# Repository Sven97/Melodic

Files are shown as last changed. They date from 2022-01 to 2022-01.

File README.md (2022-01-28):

# Melodic

[GitHub Address](https://github.com/Sven97/Melodic)

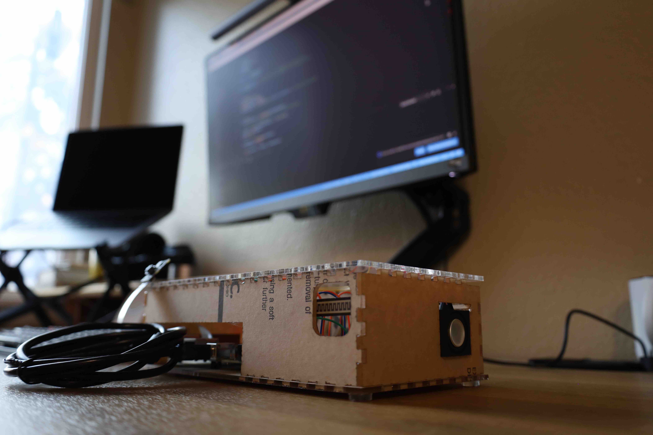
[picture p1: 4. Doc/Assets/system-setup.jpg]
system setup


## 0. About

An integrated system providing speech therapy service via software and hardware at low cost.

This repo contains the code and the instructions for Imagine Cup project Melodic submission.

The image below shows the simplified data flow or the pipeline between our hardware and software

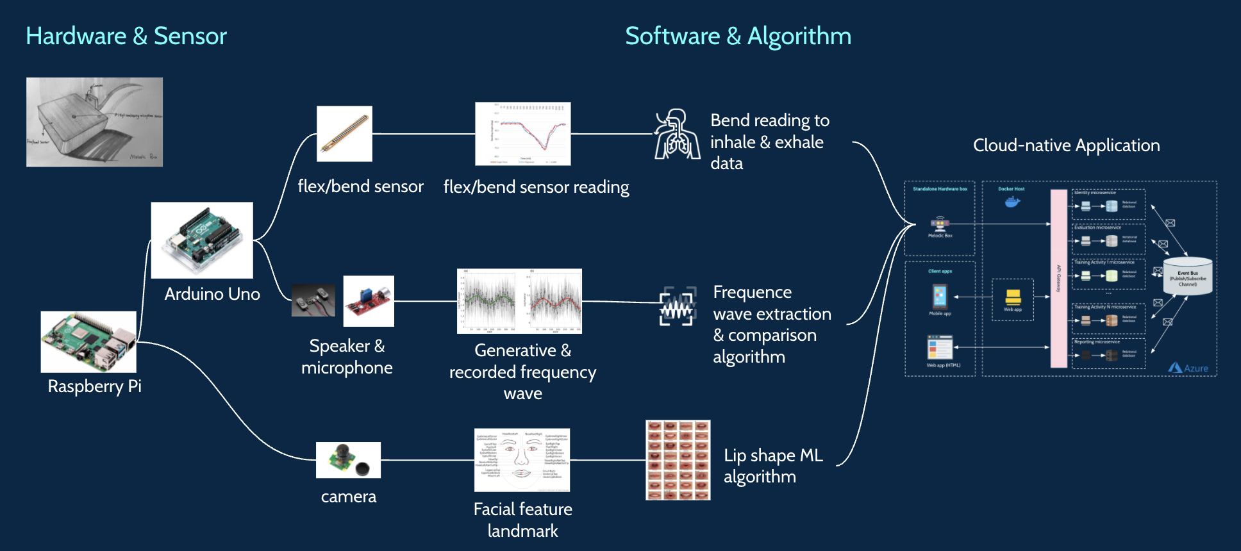
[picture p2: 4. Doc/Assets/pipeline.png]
pipeline


## 1. Hardware

## 1.1 Hardware Requirements

The hardware listed below is the minimum requirement to run our system. The details and purchase links of the sensors and boards will be covered in the **Hardware** folder

- 1x Raspberry Pi 4 Model B
- 1x Arduino Uno
- 1x High Quality Pi Camera
- 1x Sound Sensor
- 1x Speaker
- 1x Flex resistor (flex sensor)
- 1x Push Button (for debug)
- 1x Potentiometer (for debug)
- 1x breadboard
- Multiple jump wires
- Laser Cut Case

## 1.2 Circuit Diagram

This is basic circuit setup of our sensors and boards. The sound sensor, flex sensor, speaker, push button, and potentiometer are connected to Arduino, and the HQ pi camera is connected to raspberry pi 

circuit diagram

## 1.3 Raspberry Pi and Arduino for Serial communication.

There are 2 ways to connect your Raspberry Pi and Arduino for Serial communication.

### Serial via USB.

On the Raspberry Pi side, a simple USB connector is all you need. You can choose any of the 4 USB ports available on the board.

For Arduino, you will use the USB port that you use to upload code from your computer (with the Arduino IDE) to your board. Here the USB connector will depend on which version you have. For boards like Arduino Uno and Mega, the connector will be different from Arduino Nano, and from Arduino Zero.

For this project I’ve used an Arduino Uno board.
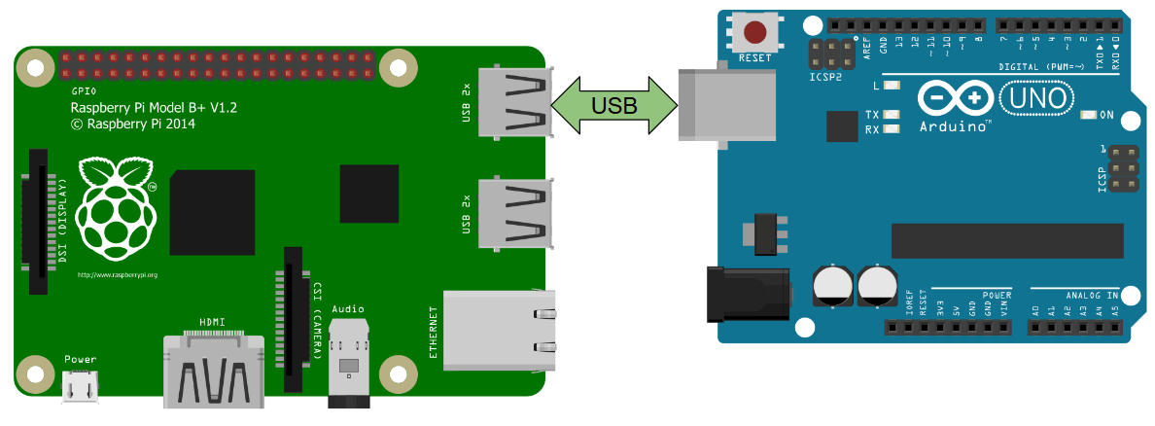
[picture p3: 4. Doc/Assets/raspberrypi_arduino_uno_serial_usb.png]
serial communication


### Serial via GPIOs

To make a Serial connection you can also use plain wires between the Raspberry Pi GPIOs and the Arduino pins.

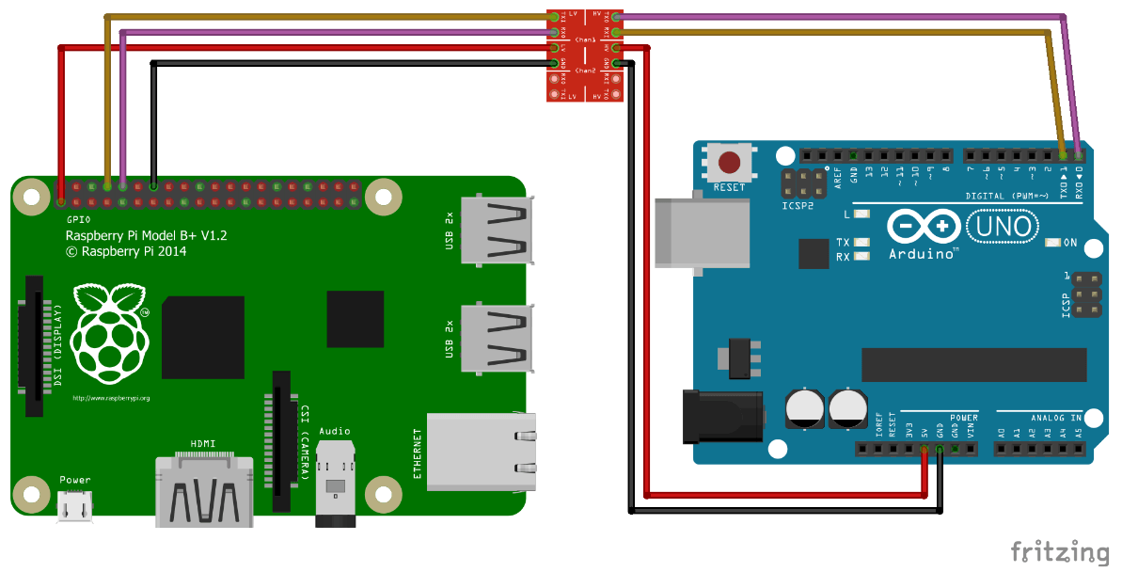
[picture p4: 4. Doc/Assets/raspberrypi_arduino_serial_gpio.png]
serial gpio


Depending on your Arduino board you might need to use a voltage level-shifter. The Raspberry Pi is operating at 3.3V. For Arduino boards like Due, 101, it will be fine because they also use 3.3V.

But, for many Arduino, such as Uno, Mega, Leonardo, Nano, and many more, the board is operating at 5V. Thus, you need a 3.3V/5V level-shifter to protect the Raspberry Pi when connecting RX and TX (more info on Raspberry Pi pins and Arduino Uno pins).

## 1.4 Case Design

There are two versions of the laser cut svg file in **3. Case Design** folder. The debug version is designed for debug purpose with a lot of free space inside the case and easy access to all the ports for both boards. The compact version is designed for final product with a compact design.

case cut file

# 2. Environment Setup

## 2.1 Flashing 'Buster' OS onto a Raspberry Pi

We will be running face mesh extraction on the raspberry pi. Currently, we are using mediapipe and open-cv for this purpose. We need to install mediapipe and open-cv on the raspberry pi. 

Until there is correct compatibility of opencv with the new Raspberry Pi ‘Bullseye’ OS, I highly recommend at this stage flashing and using the previous Raspberry Pi ‘Buster’ OS onto your Micro-SD. This is a [guide](https://core-electronics.com.au/tutorials/flash-buster-os-pi.html) for how to flash the old 'Buster' Raspberry Pi OS to a Micro-SD.

## 2.2 Setting Up Raspberry PI with High Quality Camera 

Connect the Ribbon Cable to the CSI (Camera Serial Interface) connector on the Raspberry Pi board and to the Camera module. You can see all these assembly steps in the images below. To connect the ribbon cables, lift up the edges of the CSI connector gently, slip the ribbon cable in till it bottoms out, then push down the edges of the CSI connector.

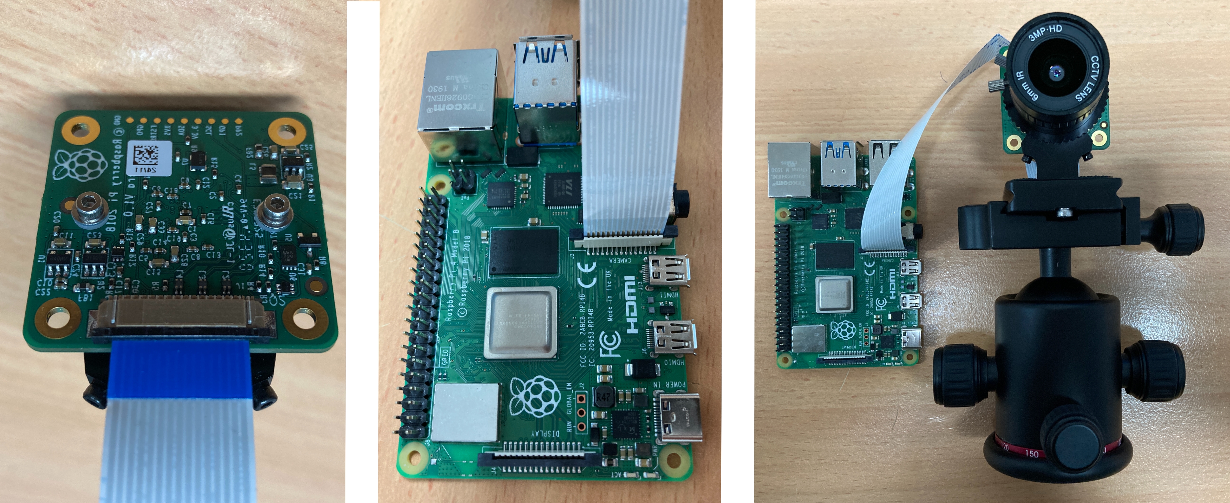
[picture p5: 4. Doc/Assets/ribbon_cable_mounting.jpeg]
ribbon_cable_mounting


With the Micro-SD Card flashed you can install it into your Raspberry Pi. Now connect all the peripheries and plug in the USB C to turn on the Raspberry Pi. Then open up the Raspberry Pi Configuration menu (found using the top left menu and scrolling over preferences) and enable the Camera found under the Interfaces tab. After enabling reset the Raspberry Pi to lock in the changes. See the image below for the setting location.

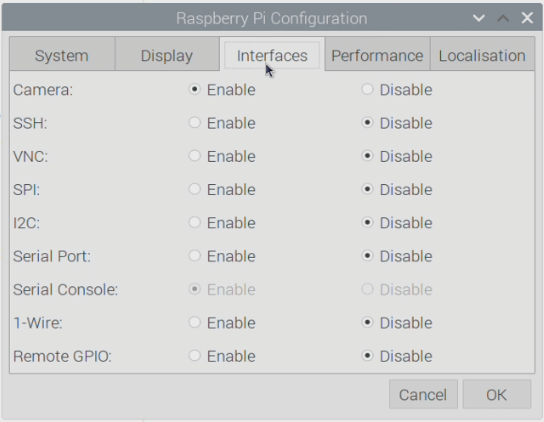
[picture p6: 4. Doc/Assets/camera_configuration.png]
camera configuration


Use following command in the pi terminal to check whether the camera is running properly. This command will capture a image using the camera and save it as 'image.jpg' at root folder.

```bash
raspistill -o image.jpg
```

## 2.3 Setting up opencv on Raspberry Pi 'Buster' OS
Open up the Terminal by pressing the Terminal Button found on the top left of the button. Copy and paste each command into your Pi’s terminal, press Enter, and allow it to finish before moving onto the next command. If ever prompted, “Do you want to continue? (y/n)” press Y and then the Enter key to continue the process.

```bash
sudo apt-get update && sudo apt-get upgrade
```

We must now expand the swapfile before running the next set of commands. To do this type into terminal this line.

```bash
sudo nano /etc/dphys-swapfile
```            

The change the number on `CONF_SWAPSIZE = 100` to `CONF_SWAPSIZE=2048`. Having done this press Ctrl-X, Y, and then Enter Key to save these changes. This change is only temporary and you should change it back after completing this. To have these changes affect anything we must restart the swapfile by entering the following command to the terminal. Then we will resume Terminal Commands as normal.

```bash
sudo apt-get install build-essential cmake pkg-config
sudo apt-get install libjpeg-dev libtiff5-dev libjasper-dev libpng12-dev
sudo apt-get install libavcodec-dev libavformat-dev libswscale-dev libv4l-dev
sudo apt-get install libxvidcore-dev libx264-dev
sudo apt-get install libgtk2.0-dev libgtk-3-dev
sudo apt-get install libatlas-base-dev gfortran
sudo pip3 install numpy
```

```bash
wget -O opencv.zip https://github.com/opencv/opencv/archive/4.4.0.zip
wget -O opencv_contrib.zip https://github.com/opencv/opencv_contrib/archive/4.4.0.zip
unzip opencv.zip
unzip opencv_contrib.zip
cd ~/opencv-4.4.0/
mkdir build
cd build
cmake -D CMAKE_BUILD_TYPE=RELEASE \
                                -D CMAKE_INSTALL_PREFIX=/usr/local \
                                -D INSTALL_PYTHON_EXAMPLES=ON \
                                -D OPENCV_EXTRA_MODULES_PATH=~/opencv_contrib-4.4.0/modules \
                                -D BUILD_EXAMPLES=ON ..

make -j $(nproc)
```

This ` make ` Command will take over an hour to install and there will be no indication of how much longer it will take. It may also freeze the monitor display. Be ultra patient and it will work. Once complete you are most of the way done. If it fails at any point and you receive a message like ` make: *** [Makefile:163: all] Error 2 ` just re-type and enter the above line ` make -j $(nproc) `. Do not fear it will remember all the work it has already done and continue from where it left off. Once complete we will resume terminal commands.

```bash
sudo make install && sudo ldconfig
sudo reboot
```

## 2.4 Necessary Packages or Library

Open the terminal on the raspberry pi or using SSH to connect to the raspberry pi. Enter the following command to install necessary package.

```bash
sudo apt-get update && sudo apt-get upgrade
sudo apt-get install python-opencv python3-opencv opencv-data
sudo pip3 install mediapipe-rpi3
sudo pip3 install mediapipe-rpi4
sudo pip3 install gtts
sudo apt install mpg321
```

## 2.5 Raspberry pi and Arduino Serial Communication

The hardware setup for serial communication between raspberry pi and arduino is introduce in 1.3. Next is software setup.

### Detect the Arduino board

When connecting the Arduino with a USB cable, you should see it appear as `/dev/ttyACM0`, or `/dev/ttyUSB0` (sometimes the number can be different, for example `/dev/ttyACM1`).

Simply run `ls /dev/tty*` and you should see it. At this point if you’re not sure which device is the Arduino board, simply disconnect the board (remove the USB cable), and run `ls /dev/tty*` again. This way you will easily spot the serial device name of your Arduino.

### Hardware permissions for Serial

Also, you may want to add your user to the dialout group, to avoid errors such as: `serial.serialutil.SerialException: [Errno 13] could not open port /dev/ttyACM0: [Errno 13] Permission denied: ‘/dev/ttyACM0’`.

```bash
sudo adduser your_username dialout
```

This will make sure you have access to Serial devices (/dev/ttyACMx, /dev/ttyUSBx, …).

After you’ve added yourself to the dialout group, you need to reboot your Pi (or at least logout/login) to apply the change

### Install Python Serial library on Raspberry Pi

You need to install a library to be able to use the Serial interface with Python.

For this tutorial we’ll use the pySerial library (documentation for Python 3). To install it:

```bash
python3 -m pip install pyserial
```

This Python library is well-known and used in a lot of applications.

When installing, if you get an error such as `/usr/bin/python3: No module named pip`, then you need to install pip first with `sudo apt install python3-pip`.

Follow the step in **3. Software/serial communication test** to test the bidirectional_serial_communication

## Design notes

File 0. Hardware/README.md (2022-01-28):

# Hardware List

| **Item** | **Unit Cost** | **Qty** | **Total** | 
|---|---|---|---|
| pi camera | $30 | 1 | $30 |
| raspberry pi | $55 | 1 | $55 |
| arduino uno | $23 | 1 | $23 |
| bend sensor | $10 | 1 | $10 |
| sound sensor | $4 | 1 | $4 |
| speaker | $7 | 1 | $7 |
| est packaging &  fastener | $5 | 1 | $5 |
| | | | $134 |

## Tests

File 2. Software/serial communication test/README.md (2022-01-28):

# Bidirectional Serial Communication Test between Raspberry Pi and Arduino

This is a test to check the serial communication between Raspberry Pi can Arduino.

## Arduino Code
Here we check if the Arduino has received data with Serial.available(). This will give you the number of bytes already arrived and stored in the receive buffer.

If some data has arrived, we use Serial.readStringUntil() with a newline character ‘\n’ to get the next line. This is similar to the readline() function. All the bytes received until ‘\n’ are automatically converted and added in an Arduino String object.

Then, we just print back the data we received, with an additional piece of text.

## Raspberry Pi Python Code

Use the pySerial function write() to send data to the Arduino. Here you can see that I’ve added a ‘b’ before the string to send. This will encode the string to bytes, because you can only send bytes through Serial. Any data which is not a byte or byte array must be converted before being sent. If you just try to send the string like that, you’ll get this error ” TypeError: unicode strings are not supported, please encode to bytes: ‘Hello from Raspberry Pi!’ ”

Also, we add a newline character ‘\n’ because that’s what the Arduino is expected to end its reading with Serial.readStringUntil(‘\n’).

Then, we do the same thing as we did before: we read a line, decode it to string, and remove any trailing character. We’re not using the ser.in_waiting here, because for this specific application we know that the Arduino will send back some data just after it has received the string. Also, we have a 1 second timeout to avoid being stuck on this line.

Finally, we print the received string and wait for 1 second with time.sleep() before sending the next string over Serial.

## Testing bidirectional Serial communication

On your Raspberry Pi, make your Python file executable and launch it.

```bash
$ chmod +x bidirectional_serial_communication.py 
$ ./bidirectional_serial_communication.py 
You sent me: Hello from Raspberry Pi!
You sent me: Hello from Raspberry Pi!
You sent me: Hello from Raspberry Pi!
```

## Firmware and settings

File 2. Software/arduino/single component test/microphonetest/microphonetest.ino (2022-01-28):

/*
 File/Sketch Name: AudioFrequencyDetector

 Version No.: v1.0 Created 12 December, 2019
 
 Original Author: Clyde A. Lettsome, PhD, PE, MEM
 
 Description:  This code/sketch makes displays the approximate frequency of the loudest sound detected by a sound detection module. For this project, the analog output from the 
 sound module detector sends the analog audio signal detected to A0 of the Arduino Uno. The analog signal is sampled and quantized (digitized). A Fast Fourier Transform (FFT) is
 then performed on the digitized data. The FFT converts the digital data from the approximate discrete-time domain result. The maximum frequency of the approximate discrete-time
 domain result is then determined and displayed via the Arduino IDE Serial Monitor.

 Note: The arduinoFFT.h library needs to be added to the Arduino IDE before compiling and uploading this script/sketch to an Arduino.

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
 Notes: Copyright (c) 2019 by C. A. Lettsome Services, LLC
 For more information visit https://clydelettsome.com/blog/2019/12/18/my-weekend-project-audio-frequency-detector-using-an-arduino/

*/

#include "arduinoFFT.h"
 
#define SAMPLES 128             //SAMPLES-pt FFT. Must be a base 2 number. Max 128 for Arduino Uno.
#define SAMPLING_FREQUENCY 2048 //Ts = Based on Nyquist, must be 2 times the highest expected frequency.
 
arduinoFFT FFT = arduinoFFT();
 
unsigned int samplingPeriod;
unsigned long microSeconds;
 
double vReal[SAMPLES]; //create vector of size SAMPLES to hold real values
double vImag[SAMPLES]; //create vector of size SAMPLES to hold imaginary values
 
void setup() 
{
    Serial.begin(115200); //Baud rate for the Serial Monitor
    samplingPeriod = round(1000000*(1.0/SAMPLING_FREQUENCY)); //Period in microseconds 
}
 
void loop() 
{  
    /*Sample SAMPLES times*/
    for(int i=0; i<SAMPLES; i++)
    {
        microSeconds = micros();    //Returns the number of microseconds since the Arduino board began running the current script. 
     
        vReal[i] = analogRead(A1); //Reads the value from analog pin 0 (A0), quantize it and save it as a real term.
        vImag[i] = 0; //Makes imaginary term 0 always

        /*remaining wait time between samples if necessary*/
        while(micros() < (microSeconds + samplingPeriod))
        {
          //do nothing
        }
    }
 
    /*Perform FFT on samples*/
    FFT.Windowing(vReal, SAMPLES, FFT_WIN_TYP_HAMMING, FFT_FORWARD);
    FFT.Compute(vReal, vImag, SAMPLES, FFT_FORWARD);
    FFT.ComplexToMagnitude(vReal, vImag, SAMPLES);

    /*Find peak frequency and print peak*/
    double peak = FFT.MajorPeak(vReal, SAMPLES, SAMPLING_FREQUENCY);
    if(peak>80 && peak<300){
      Serial.println(peak);     //Print out the most dominant frequency.
    }
    
 
//    /*Script stops here. Hardware reset required.*/
//    while (1); //do one time
}

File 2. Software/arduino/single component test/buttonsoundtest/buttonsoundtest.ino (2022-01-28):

#include "pitches.h"

const int buttonPin = 2;  // pushbutton pin
const int speakerPin = 8;  // speaker pin
const int potentiometerPin = A0; 

int noteDuration = 1000;

void setup() {
  // Set up the pushbutton pins to be an input:
  pinMode(buttonPin, INPUT);

  // Set up the speaker pin to be an output:
  pinMode(speakerPin, OUTPUT);

  Serial.begin(115200);
}

void loop() {
  int potentiometerValue;
  potentiometerValue = analogRead(potentiometerPin);
  
  int frequency;
  // voice frequency adult male 85-155 Hz, adult female 165-255 Hz
  // speaker produce 80-300 Hz sound
  frequency = map(potentiometerValue, 0, 1023,80,300);
//  frequency = int((float(potentiometerValue) / 1023.0) * 220.0)+80;
  Serial.println(frequency);
  // variables to hold the pushbutton states
  int buttonState;
  buttonState = digitalRead(buttonPin);

  if (buttonState == LOW)
  {
    tone(speakerPin, frequency, noteDuration);
  }
  else
  {
    noTone(speakerPin);
  }

}

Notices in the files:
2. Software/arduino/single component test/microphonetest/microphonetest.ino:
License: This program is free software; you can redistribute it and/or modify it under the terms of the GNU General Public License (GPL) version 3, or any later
